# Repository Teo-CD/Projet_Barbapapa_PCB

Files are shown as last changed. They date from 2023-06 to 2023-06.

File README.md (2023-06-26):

# Projet Barbapapa - Carte électronique

Le Projet Barbapapa est un projet surprise qui réunit des anciens JINs.

L'une des parties de ce projet est un objet intéractif, ce dépôt en contient
la conception électroniques, réalisée avec [KiCad](https://www.kicad.org/).

# Objectifs

La carte électronique doit permettre la détection de tags RFID, le contrôle 
d'un écran LCD, de LEDs RGB, ainsi que l'utilisation d'un haut-parleur.

Elle doit permettre une opération connectée à un ordinateur, comme indépendante.

# État

**Révision 1.0**  

La production de la carte a été lancée, mais pas encore testée.

La versionnement de forme X.Y se lit comme suit:
 - X : Version mise en production (avec 1 comme première production)
 - Y : Révision suivant la mise en production (remis à 0 quand X augmente)

# Choix

## Fabricant

La carte a été conçue pour être fabriquée par JLCPCB en double couche avec une carte de 0.8mm d'épaisseur. Les marges
du design ont donc été pensées pour leurs capacités de fabrication.  
Le choix du 0.8mm est essentiellement pour faciliter l'atteinte de la bonne impédance pour les pistes D+ et D- de l'USB.  
JLCPCB a aussi le gros avantage d'être très bon marché, en passant en double couche les PCBs devraient coûter à peine
quelques livres.

## Carte microcontrôleur

La teensy 4.1 a été choisie pour la flexibilité de ses interfaces et des bibliothèques disponnibles.  
La carte elle-même est bien trop puissante pour l'application, qui ne nécessite pas la capacité de calcul d'un Cortex-M7,
mais cela réduira les contraintes lors du développement du firmware pour faire tourner les différents éléments.

En particulier, les bibliothèques audio de la teensy sont assez réputées et ont servies pour faire différentes pédales
d'effet, et la présence d'un port microSD déjà intégré sur la carte rend le stockage des animations pour le LCD et des
fichiers audios bien plus simple.

## Alimentation

Une des contraintes de conception était la possibiltié d'utiliser l'objet de façon indépendante d'un ordinateur. Il a donc
fallut intégrer une batterie capable de tenir la charge du système.

L'élément le plus consommateur ici est l'amplificateur audio. Bien que la majeure partie du temps il ne consomme presque rien,
les pics de courant demandés lors du jeu audio ont poussé au choix d'une batterie Li-Ion et d'un régulateur pouvant soutenir
2A de courant continu.

Les batteries Li-Ion ont l'avantage monter à 4.2V à pleine charge, il est donc possible de les charger par USB. Cela évite
l'utilisation de piles non-rechargeables, que je voulais éviter. Elles permettent aussi de débiter un courant suffisant pour
alimenter tout le système, ce qui est rarement le cas des piles jetables de toutes façons.

Le système est donc alimenté par la batterie, parfois complémenté par le chargeur qui fournit jusqu'à 500mA pour la charger.
Seule la Teensy est alimentée directement par la batterie, tout le reste du système est derrière le régulateur 3.3V (tension
logique de la Teensy).

L'alimentation à la Teensy est contrôlée par un interrupteur externe branché sur `SW2`, puis cette dernière contrôle l'activation
du régulateur 3.3V. Elle peut lire la tension fournie par la batterie et décider de couper le système si nécessaire pour la
préserver.  

### À noter

Le gros du système est protégé d'une inversion de polarité de la batterie Li-Ion par une diode. Cependant, le chargeur lui-même
ne l'est pas. Cette décision à été prise car l'inversion ne devrait pas être trop commune, le réceptacle étant polarisé et indiqué,
mais aussi pour la chute de tension supplémentaire que ça aurait apporté.

***Ne pas mettre la batterie à l'envers !***

## Périphériques

La carte est conçue pour la connexion d'un écran LCD de Nokia 5110 pour son style à gros pixels et d'un module NFC.  

Le module NFC choisi est le RC522 pour sa capacité à gérer de multiples tags dans sa zone de détection et ainsi permettre de
poser plusieurs figurines sur la zone en même temps.  

Au cas où la zone de détection s'avère trop faible ou que la connexion du module NFC et du module LCD au même bus SPI soit
problématique, deux alternatives ont été prévues sur la carte :  
 1. La possibilité d'utiliser du soft-SPI pour le LCD
 2. La sortie d'un deuxième bus SPI indépendant pour un deuxième module NFC en parallèle

L'amplificateur a été choisi pour son entrée I2S (signal audio numérique) et son circuit d'amplification très complet et
auto-suffisant, ne nécessitant pas grand chose de plus que quelques condensateurs et résistances pour le choix de fonctionnement.  
C'est un MAX98357A, il existe aussi sous forme de module entre autre par Sparkfun comme "I2S Audio Breakout".  

Deux autres séries de broches sont présentes : une pour brancher un câble FTDI et avoir accès à la série de la Teensy directement
(seules les broches TX/RX et la masse sont connectées) et un trois broches pour contrôler des LEDs RGB addressables style neopixel.

# License

Les éléments présents dans ce dépôt sont Open Source Hardware, sous license [CERN Open Hardware Licence Version 2 - Weakly Reciprocal](https://ohwr.org/cern_ohl_w_v2.txt).

# Crédits

Carte conçue par Téo-CD, avec les conseiles de Victor Védie, François Charles, Lucas Molia.

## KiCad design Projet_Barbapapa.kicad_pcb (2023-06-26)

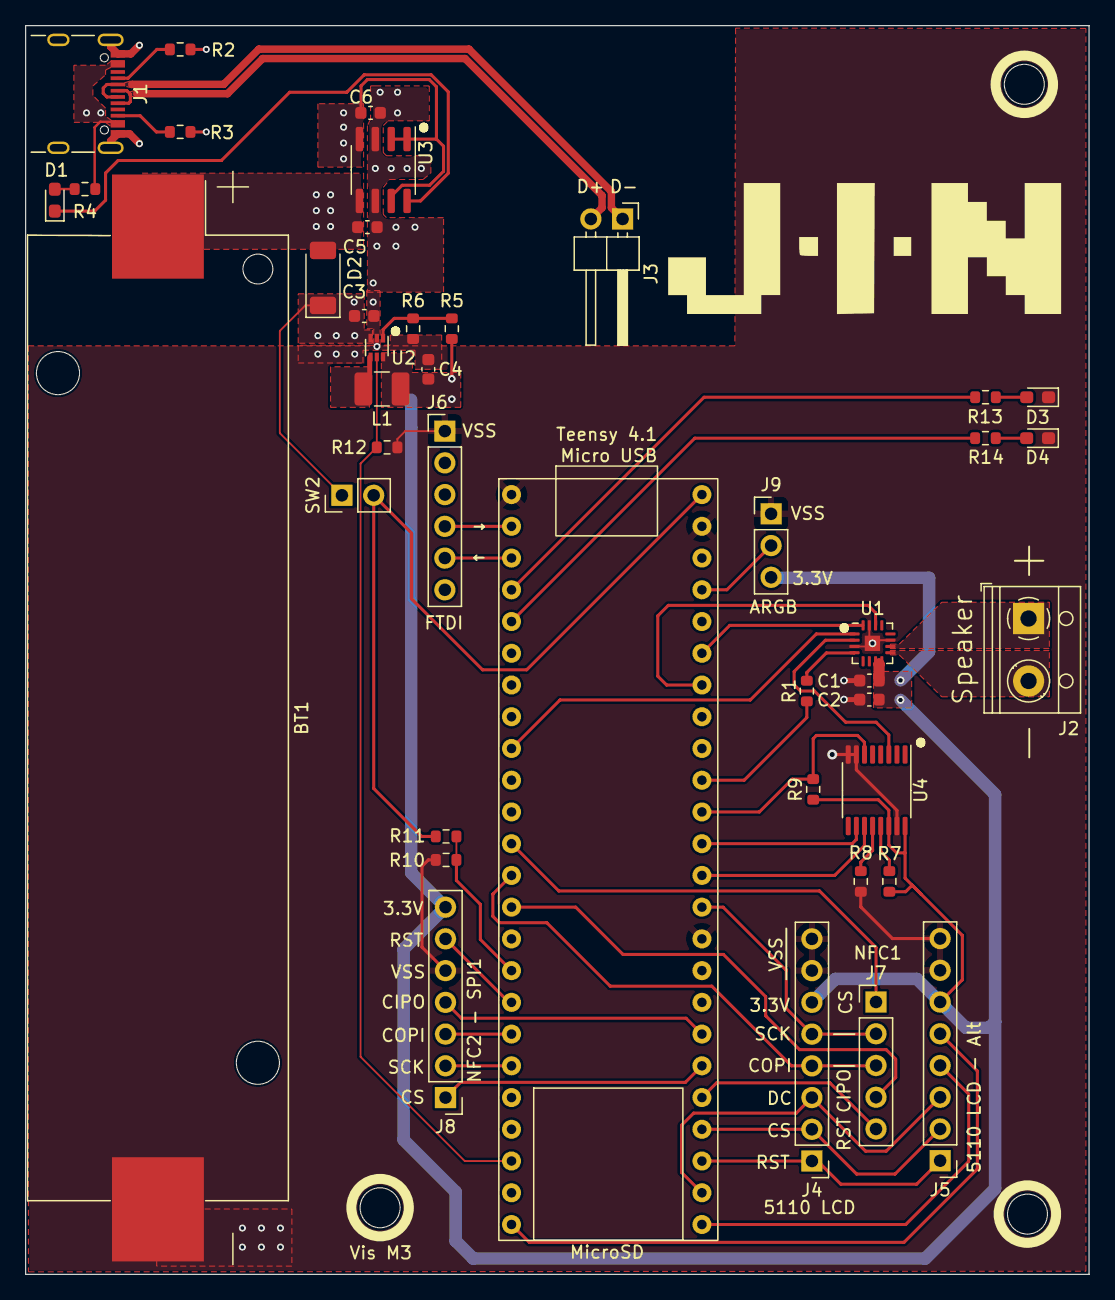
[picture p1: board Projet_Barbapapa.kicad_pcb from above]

Board: 2 copper layers, 85.1 x 99.9 mm, 44 parts (0 on the bottom side), 51 nets.

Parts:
BT1: Battery_Cell; BatteryHolder_Keystone_1042_1x18650
C1: CAP_0603_100nF_50V; CAP_0603
C2, C3, C4, C5, C6: CAP_0603_10uF_50V; CAP_0603
D1, D3, D4: LED; LED_0603_1608Metric_Pad1.05x0.95mm_HandSolder
D2: PMEG3050EP-QX; D_SOD-128
H1, H2, H3: MountingHole; MountingHole_3.2mm_M3
J1: USB_C_Receptacle_USB2.0; USB_C_Receptacle_GCT_USB4105-xx-A_16P_TopMnt_Horizontal
J2: Speaker; TerminalBlock_RND_205-00012_1x02_P5.00mm_Horizontal
J3: Conn_01x02; PinHeader_1x02_P2.54mm_Horizontal
J4: LCD SPI; PinHeader_1x08_P2.54mm_Vertical
J5: LCD Soft SPI; PinHeader_1x08_P2.54mm_Vertical
J6: Random FTDI; PinHeader_1x06_P2.54mm_Vertical
J7: NFC1; PinHeader_1x05_P2.54mm_Vertical
J8: NFC2; PinHeader_1x07_P2.54mm_Vertical
J9: RGB_LED; PinHeader_1x03_P2.54mm_Vertical
L1: IND_1.5uH_5A_20%; L_1210_3225Metric_Pad1.42x2.65mm_HandSolder
R1: RES_0603_634K_1%; RES_0603
R2, R3, R9, R12: RES_0603_5K1_1%; RES_0603
R4, R13, R14: RES_0603_200_1%; RES_0603
R5, R10: RES_0603_200k_1%; RES_0603
R6: RES_0603_44K2_1%; RES_0603
R7, R8, R11: RES_0603_100K_1%; RES_0603
SW2: Power switch; PinHeader_1x02_P2.54mm_Vertical
Teensy 4.1: Teensy 4.1
U1: MAX98357A/B; TQFN-16-1EP_3x3mm_P0.5mm_EP1.23x1.23mm
U2: AP61201Z6-7 buck; SOT-563
U3: MAX1811; SOIC-8_3.9x4.9mm_P1.27mm
U4: CD4051B; TSSOP-16_4.4x5mm_P0.65mm

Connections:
/ARGB_Data: J9.2, Teensy 4.1.23
/Audio/AMP_GAIN0: Teensy 4.1.14, U4.11 (A)
/Audio/AMP_GAIN1: Teensy 4.1.15, U4.10 (B)
/Audio/AMP_GAIN_EN: R9.2, Teensy 4.1.16, U4.6 (INH)
/Audio/Amp_enable: R1.1, Teensy 4.1.17
/Audio/BCLK: Teensy 4.1.21 (A7), U1.16 (BCLK)
/Audio/LRCLK: Teensy 4.1.20 (A6), U1.14 (LRCLK)
/Audio/Speaker_N: J2.2, U1.9 (OUTP)
/Audio/Speaker_P: J2.1, U1.10 (OUTN)
/Audio_OUT: Teensy 4.1.7 (OUT1A), U1.1 (DIN)
/BAT_SNS: R10.2, R11.1, Teensy 4.1.24 (A10)
/DBG_LED_1: R13.1, Teensy 4.1.2 (OUT2)
/DBG_LED_2: R14.2, Teensy 4.1.3 (LRCLK2)
/LCD connectors/LCD_COPI_ALT: J5.4, Teensy 4.1.33 (MCLK2)
/LCD connectors/LCD_CS: J4.2, J5.2, Teensy 4.1.36 (CS)
/LCD connectors/LCD_DC: J4.3, J5.3, Teensy 4.1.34 (RX8)
/LCD connectors/LCD_RST: J4.1, J5.1, Teensy 4.1.35 (TX8)
/LCD connectors/LCD_SCK_ALT: J5.5, Teensy 4.1.32 (OUT1B)
/NFC1_RST: J7.5, Teensy 4.1.37
/NFC2_CS: J8.1, Teensy 4.1.38 (A14)
/NFC Connectors/NFC1_CS: J7.1, Teensy 4.1.10 (CS)
/NFC Connectors/NFC2_RST: J8.6, Teensy 4.1.25 (A11)
/Power and USB/BATT_LOAD: BT1.1 (+), C5.2, D2.2 (A), U3.5 (BATT)
/Power and USB/BATT_SAFE: C3.1, D2.1 (K), SW2.1 (A), U2.3 (VIN)
/Power and USB/USB_D_N: J1.A7 (D-), J1.B7 (D-), J3.1
/Power and USB/USB_D_P: J1.A6 (D+), J1.B6 (D+), J3.2
/Power and USB/VBUS: C6.2, J1.A4 (VBUS), J1.A9 (VBUS), J1.B4 (VBUS), J1.B9 (VBUS), R4.2, U3.1 (SELV), U3.2 (SELI), U3.4 (IN), U3.7 (EN)
/Power and USB/VIN: R11.2, SW2.2 (B), Teensy 4.1.60 (Vin)
/Reg_en: R12.1, Teensy 4.1.30, U2.5 (EN)
/SPI1_CIPO: J8.4, Teensy 4.1.39 (A15)
/SPI1_COPI: J8.3, Teensy 4.1.26 (A12)
/SPI1_SCK: J8.2, Teensy 4.1.27 (A13)
/SPI_CIPO: J7.4, Teensy 4.1.12 (CIPO)
/SPI_COPI: J4.4, J7.3, Teensy 4.1.11 (COPI)
/SPI_SCK: J4.5, J7.2, Teensy 4.1.13 (SCK)
unnamed: D1.2 (A), R4.1
unnamed: D1.1 (K), U3.8 (~CHG)
unnamed: D3.2 (A), R13.2
unnamed: D4.2 (A), R14.1
unnamed: J1.A5 (CC1), R2.1
unnamed: J1.B5 (CC2), R3.2
unnamed: J6.4, Teensy 4.1.0 (RX1)
unnamed: J6.5, Teensy 4.1.1 (TX1)
unnamed: U1.2 (~GAIN_SLOT), U4.3 (X)
unnamed: R1.2, U1.4 (~SD_MODE)
unnamed: R5.1, R6.2, U2.1 (FB)
unnamed: L1.1, U2.4 (SW)
unnamed: R7.2, U4.13 (X0)
unnamed: R8.2, U4.12 (X3)
VDD: C1.1, C2.1, C4.2, J4.6, J5.6, J8.7, J9.3, L1.2, R5.2, R7.1, R9.1, U1.7 (VDD), U1.8 (VDD), U2.6 (OUT), U4.14 (X1), U4.16 (VDD)
VSS: BT1.2 (-), C1.2, C2.2, C3.2, C4.1, C5.1, C6.1, D3.1 (K), D4.1 (K), J1.A1 (GND), J1.A12 (GND), J1.B1 (GND), J1.B12 (GND), J1.S1 (SHIELD), J4.7, J4.8, J5.7, J5.8, J6.1, J8.5, J9.1, R2.2, R3.1, R6.1, R8.1, R10.1, R12.2, Teensy 4.1.50 (GND), Teensy 4.1.57 (GND), Teensy 4.1.59 (GND), U1.3 (GND), U1.11 (GND), U1.15 (GND), U1.17 (GND), U2.2 (GND), U3.3 (GND), U3.6 (GND), U4.7 (VEE), U4.8 (VSS), U4.15 (X2)

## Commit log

2023-06-19 Première révision carte complète
    La carte est planifiée et routée avec un minimum de choses fonctionelles
    Il reste beaucoup de questions:
    - Comment faire la dissipation thermique proprement ?
    - Où/comment mettre les vias ?
    - Routage OK ?
    - Coupure à basse charge de batterie ?
    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
    [Audio.kicad_sch, LCD_connectors.kicad_sch, NFC_Connectors.kicad_sch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]
2023-06-22 Améliorations après retour Victor
    Allumage du régulateur maintenant géré par la teensy
    Compaction de la carte pour rentrer sur 100x100mm
    Ajout des trous de montage
    Routage de la puissance du port USB maintenant sans boucle !
    Un peu plus d'espace pour l'ampli'
    Routage de l'ampli' avec des plans sur la sortie et une via par
    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
    [Audio.kicad_sch, LCD_connectors.kicad_sch, NFC_Connectors.kicad_sch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]
2023-06-22 Inversion de la bobine de régulateur
    180° à la bobine du régulateur pour faciliter le routage et le placement
    Plus d'espace autour du régulateur.
    [Projet_Barbapapa.kicad_pcb]
2023-06-25 Rev 0.3: Passage sur deux couches
    Passage sur deux couches, ajustement de l'impédance pour l'USB.
    Reroutage de l'alimentation côté USB
    Ajout de beaucoup de silk
    Quelques ajustements de nets pour la lisbilité
    Ajout de LEDs de debug
    Plan de masse sur le top
    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
    [Audio.kicad_sch, LCD_connectors.kicad_sch, NFC_Connectors.kicad_sch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]
2023-06-25 Étoffe le README avec les choix et raisonnements
2023-06-26 Corrections et expansion de masque
    Quelques ajustements de routage au cas où, pour VIN et une branche thermique
    sur VSS.
    Ajustement de la marge sur le plan de masse du dessus (plus grande).
    Vérification de l'expansion de masque pour le passage à 2 couches.
    [Projet_Barbapapa.kicad_pcb]
2023-06-26 Mentionne KiCad dans le README
2023-06-26 Prépare pour production de la 1.0
    [Audio.kicad_sch, LCD_connectors.kicad_sch, NFC_Connectors.kicad_sch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]
